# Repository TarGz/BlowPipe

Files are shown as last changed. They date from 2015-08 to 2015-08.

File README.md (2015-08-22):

=====
```
 		 ____   ____    _    ____    ____  _     ___  ______        ______ ___ ____  _____ 
 		/ ___| / ___|  / \  |  _ \  | __ )| |   / _ \|  _ \ \      / /  _ \_ _|  _ \| ____|
 		\___ \| |     / _ \ | | | | |  _ \| |  | | | | |_) \ \ /\ / /| |_) | || |_) |  _|  
 		 ___) | |___ / ___ \| |_| | | |_) | |__| |_| |  __/ \ V  V / |  __/| ||  __/| |___ 
 		|____/ \____/_/   \_\____/  |____/|_____\___/|_|     \_/\_/  |_|  |___|_|   |_____|	                                                       

```

=======

# A Parametric BlowPipe that works with Nerf Elite Dart
> Inspire by [Franck Youdine](https://twitter.com/fyoudine) Nerf darts paper blowpipe 

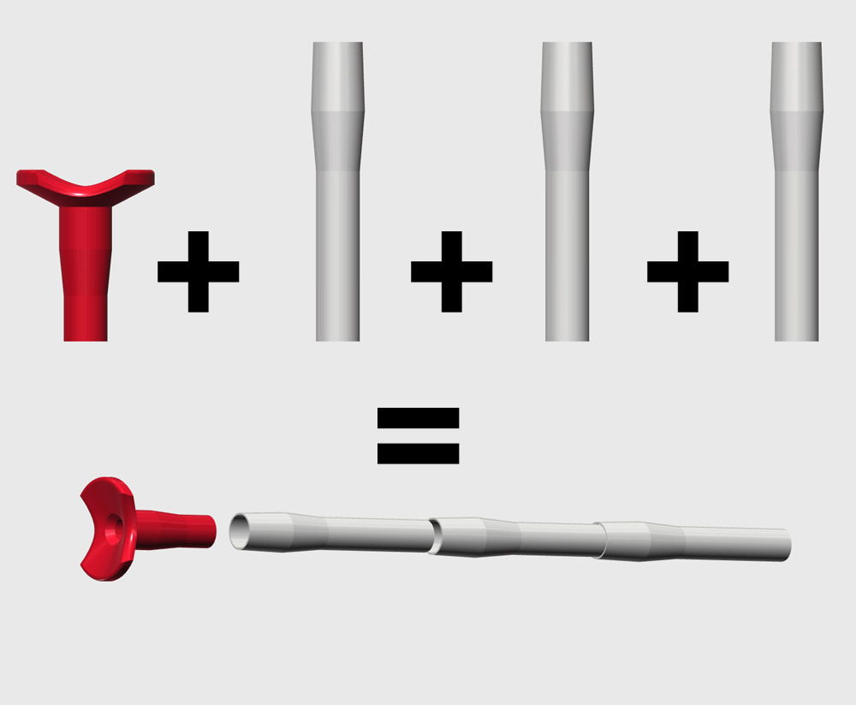
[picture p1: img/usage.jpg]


## DISCLAIMER

You are using this at your own risks, darts are relatively safe but can still hurts eyes. I can not been made responsible of any stupid things you will do with this. 

## LICENSE



Scad BlowPipe by [@targz](https://twitter.com/TarGz) is licensed under a [Creative Commons Attribution-NonCommercial 4.0 International License](http://creativecommons.org/licenses/by-nc/4.0/).

## ABOUT

This project have been tested and developed to fire Nerf Elite Dart but may be adapted to fire darts in the futur.  

Foam darts are fun, specially in office opens pace, but dart gun are not very powerful and not accurate at all.
We have used them a lot in the office and then Franck Youdine made a paper blowpipe to send darts. It was so accurate and so powerful that I decided to build one using my 3D printer.

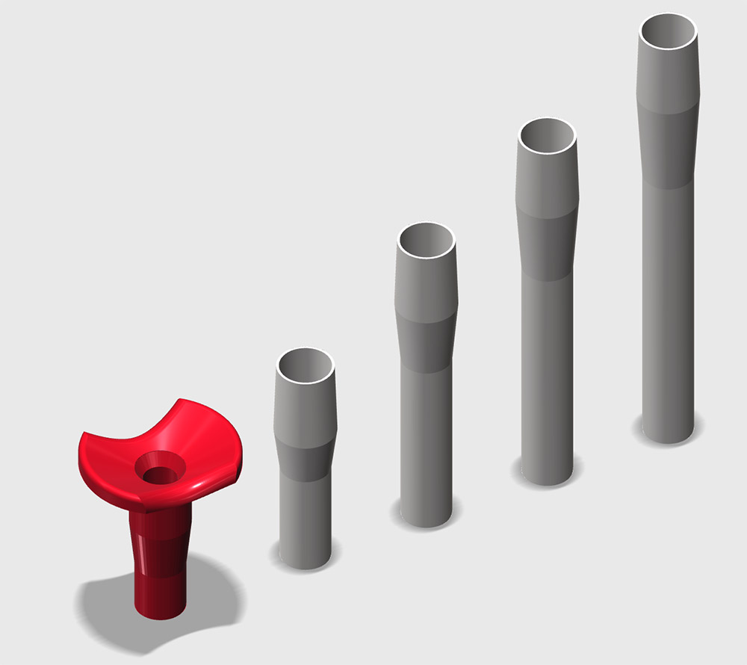
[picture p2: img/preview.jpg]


The longer the pipe the more it will be accurate, it was a bit challenging to print a long pipe has pipe need to be printed vertically. That were I came with the idea of module that could be connected and printed separately.

Depending of you printer maximum print height you can use the script to generate pipe of the perfect height. The blow module make the pipe confortable and efficient.

To stabilise the darts during the flight I get this idea of [Rifling](https://en.wikipedia.org/wiki/Rifling) so you have an option to add some groove inside the pipe. Still not sure of the efficiency, I need to get a high frame rate camera to check if the darts are rotating during the flight.

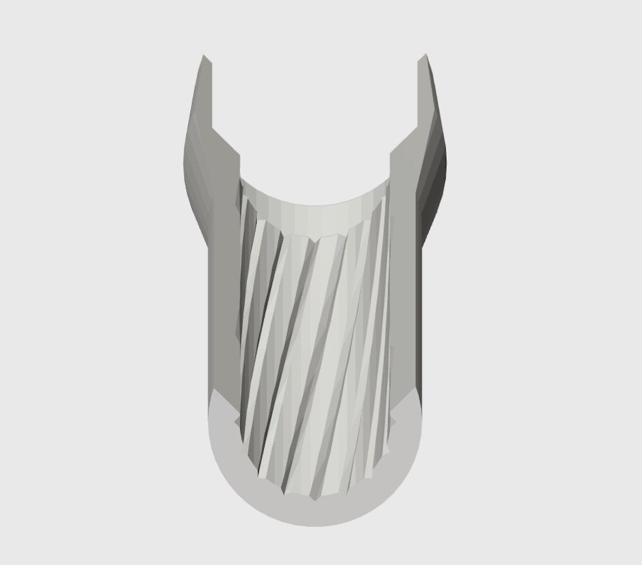
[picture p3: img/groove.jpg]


## REQUIREMENTS

You will need:

- [OpenScad](http://www.openscad.org/) free software to generate the blowpipes stl.
- A 3D printer and some PLA
- Some Nerf Elite Dart

## How to

After installing [OpenScad](http://www.openscad.org/) just use it to open the ```demo.scad``` file.
The screen should preview the pipe below. 

Then use the code below or uncomment different part of the demo file to generate your pipes.

>  First you need to include the lib

```
include <scad_blowpipe.scad>;
```

## check the demo

```
/**
 * @param {boolean} HasGroove
 */
demo(true); 
```

## generate the blow module

```
/**
 * @param {number} PipeLength
 * @param {boolean} HasGroove
 */
blow(length,groove); 
```

##  generate pipes

```
/**
 * @param {number} PipeLength
 * @param {boolean} HasGroove
 */
pipe(length,groove);
```

## ADVANCED PARAMETERS

```

/** LENGTH **/
$fn                 =   50;         // Mesh quality (number of fragments ) default:50
fix_length          =   20;         // Length of the connectors default:20
fix_ease            =   .15;        // ease between pipe to connect them default:0.15

/** PIPE **/
internal_radius     =   6.7;        // fine for standard Nerf arrow // .5 inch ? default:6.7
external_radius     =   9.5;        // radius of the pipe  default:9.5

/** ENTRANCE  **/
entrance_radius     =   6.5;        // Manage the pressure on the arrow in the entrance, more pressure = more speed = harder to blow. default:6.5
entrance_length     =   20;         // entrance length should also have an impact on speed. defaulot:20

/** GROOVE  **/
groove_twist        =   45;         // number of rotation per module default:45;
groove_size         =   1;          // Size of the groove (must not be bigger than External radius - Internal radius default:1
groove_number       =   16;         // Number of groove default:16;

```

## 3D PRINTING

Those part should be printed as they came out of the script without any support.

```
material 			: PLA
infill				: 10% 
layer heigth		: 0.3mm
Top solid layer 	: 3
Bottom solid layer 	: 3
Outline perimeter 	: 2
```

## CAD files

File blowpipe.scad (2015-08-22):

/* --------------------------------------------------------------------------------------*/
/*   ____   ____    _    ____    ____  _     ___  ______        ______ ___ ____  _____   */
/*  / ___| / ___|  / \  |  _ \  | __ )| |   / _ \|  _ \ \      / /  _ \_ _|  _ \| ____|  */
/*  \___ \| |     / _ \ | | | | |  _ \| |  | | | | |_) \ \ /\ / /| |_) | || |_) |  _|    */
/*   ___) | |___ / ___ \| |_| | | |_) | |__| |_| |  __/ \ V  V / |  __/| ||  __/| |___   */
/*  |____/ \____/_/   \_\____/  |____/|_____\___/|_|     \_/\_/  |_|  |___|_|   |_____|  */
/*                                                                                       */
/* --------------------------------------------------------------------------------------*/



/* --------------------------------------------------------------------------------------*/
/*                                                                                       */
/*           Parametric BlowPipe for Nerf darts by @targz (Julien Terraz)                */
/*           This work is licensed under the Creative Commons Attribution                */
/*           NonCommercial 4.0 International License. To view a copy of this             */
/*           license, visit http://creativecommons.org/licenses/by-nc/4.0/.              */
/*                                                                                       */
/* --------------------------------------------------------------------------------------*/



/* ------------------------------------------------------------------------------------- */
/*                                      SETTINGS                                         */
/* ------------------------------------------------------------------------------------- */

/** LENGTH **/
$fn                 =   50;         // Mesh quality (number of fragments ) default:50
fix_length          =   20;         // Length of the connectors default:20
fix_ease            =   .15;        // ease between pipe to connect them default:0.15

/** PIPE **/
internal_radius     =   6.7;        // fine for Nerf Elite Dart (.5 inch)  default radius:6.7mm
external_radius     =   9.5;        // radius of the pipe  default:9.5

/** ENTRANCE  **/
entrance_radius     =   6.5;        // Manage the pressure on the arrow in the entrance, more pressure = more speed = harder to blow. default:6.5
entrance_length     =   20;         // entrance length should also have an impact on speed. defaulot:20

/** GROOVE  **/
groove_twist        =   45;         // number of rotation per module default:45;
groove_size         =   1;          // Size of the groove (must not be bigger than External radius - Internal radius default:1
groove_number       =   16;         // Number of groove default:16;




/* ------------------------------------------------------------------------------------- */
/*                                        PUBLIC                                         */
/* ------------------------------------------------------------------------------------- */

/**  BLOW MODULE
 *
 * @param {number} PipeLength
 * @param {boolean} HasGroove
 *
 */
module blow(pl,asGroove){
    color("red") 
    rotate([180,0,0]) translate([0,0,-pl]) union(){
        blowMod(pl);
        main_pipe(pl,asGroove);
    }
}

/** BLOW PIPE   
 * 
 * @param {number} PipeLength
 * @param {boolean} HasGroove
 *
 */
module pipe(pl,asGroove){
    color("white") 
    rotate([180,0,0]) translate([0,0,-pl]) union(){
        pipeConnector(pl,asGroove);
        main_pipe(pl,asGroove);
    }
}


/** DEMO
 * 
 * @param {boolean} hasGroove
 *
 */
module demo(asGroove){
    translate([0,0,0])      blow(60,asGroove);
    translate([50,0,0])     pipe(90,asGroove);
    translate([100,0,0])    pipe(130,asGroove);
    translate([150,0,0])    pipe(160,asGroove);
    translate([200,0,0])    pipe(190,asGroove);
}

/* ------------------------------------------------------------------------------------- */
/*                        ADVANCED SETTING FROM HERE DO NOT EDIT                         */
/* ------------------------------------------------------------------------------------- */

debug                       =   false;
groove_angle                =   360 / groove_number;
fix_width                   =   2;
fix_pipe_overlap            =   1;
blow_tube_width             =   2;
blow_radius                 =   external_radius+blow_tube_width;
fix_length_blow             =   5;                      // length of the blow module connector
fix_connector_length        =   .5;         // Length ratio // deprecated
fix_connector_length_ratio  =   .2;    // Regarding the pipe length
studW                       =   3;
studH                       =   2;
studL                       =   0;
studP                       =   5;


/* ------------------------------------------------------------------------------------- */
/*                                       PRIVATE                                         */
/* ------------------------------------------------------------------------------------- */

/** STUD
    *  
    *  @param {number} width
    *  @param {number} height
    *  @param {number} heigth
    *  @param {number} depth
    *  
    */

module stud(w,l,h,d){
    echo("stud",w);
    translate([-w/2,-l/2,0]) union(){
        cube(size = [w,l,h], center = false);
        polyhedron(
          points=[  [0,-l,h],[w,-l,h],[w/2,0,h+d], 
                    [0,l,h],[w,l,h],[w/2,0,h+d] // side triangle
                    ],       
          faces=[ [2,1,0],[3,4,5],   // side triangle
                  [3,2,0],[3,5,2],[1,2,5],[4,1,5],    // roof
                  [0,1,4],[4,3,0]
                  ]  
         );
    }
}





/** GROOVES
 *
 * @param {number} PipeLength
 *
 */
module groove(pl){
    length =   pl-fix_length; 
    linear_extrude(height = length, center = false, convexity = 1, twist = groove_twist)
        translate([internal_radius+groove_size/2, 0, 0])
        rotate([0,0,-135]) polygon(points=[[0,0],[groove_size,0],[0,-groove_size]], paths=[[0,1,2]]);
}
module grooves(pl){
    color("white") union() for ( i = [0 : groove_number] ){
        rotate([0,0,groove_angle*i]) groove(pl);
    } 
}

/** MAIN PIPE
 *
 * @param {number} PipeLength
 * @param {boolean} HasGroove
 *
 */
module main_pipe(pl,asGroove){
        // MAIN PIPE
        length =   pl-fix_length; 
        translate([0, 0, fix_length]) { 
            difference(){
                color("red") difference(){
                    cylinder(length,r=external_radius);
                    translate([0, 0, -5]) cylinder(length+10,r=internal_radius);
                }
                echo("asGroove",asGroove);
                if(asGroove) grooves(pl);
            } 

        } 
        // STUD
        if(asGroove) rotate([0,0,-90-groove_twist]) translate([0, blow_radius-blow_tube_width+studH/2, length-fix_ease]) stud(studW,studH,studL,studP); 

}

/** PIPES CONNECTOR
 *
 * @param {number} PipeLength
 *
 */
module pipeConnector(pl,asGroove){
     difference(){
         // CONNECTOR
         translate([0, 0, fix_length]) {
            radius1 = external_radius+fix_width+fix_ease;
            // FIX PIPE
            color("grey")  translate([0, 0, -fix_length]) difference(){
                cylinder(fix_length,r1=external_radius+fix_width+fix_ease-1,r2=radius1);
                translate([0, 0, -5]) cylinder((fix_length)+10,r=external_radius+fix_ease);
             }
            // FIX CONNECTOR
            color("orange")  translate([0, 0, 0]) difference(){
                cylinder(pl*fix_connector_length_ratio,r1=radius1,r2=external_radius);
                translate([0, 0, -5]) cylinder((pl*fix_connector_length_ratio+10),r=external_radius);
             }   

            
         }
         // STUD
         if(asGroove) rotate([0,0,-90]) translate([0, blow_radius-blow_tube_width+studH/2, -studL]) stud(studW,studH,studL,studP);  
    }
}
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

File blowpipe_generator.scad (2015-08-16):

// ----------------------------------------------------------------------------
// Parametric BlowPipe for Nerf dart by @targz Julien Terraz
// It is licensed under the Creative Commons 1.0 Universal
// ----------------------------------------------------------------------------


// LENGTH
number_of_pipe=4;
printer_max_height = 150;
fix_length=30;
fix_connector_length=printer_max_height/2;


// PIPE
internal_radius     = 7; // do not change fine for standart Nerf arrow // .5 inch ?
entrance_radius     = 6; // manage the pressure on the arrow in the entrance
entrance_length     = 4;
external_radius     = 9.5; 



// GROOVE
groove_twist = 180; // number of rotation per module default:90;
groove_size = 2;  // Size of the groove (must not be bigger than External radius - Internal radius default:2
groove_number = 5; // Number of groove default:4;


// PRIVATE DO NOT EDIT FROM HHERE
groove_angle = 360/groove_number;
fix_ease=.5; //
fix_width = external_radius-internal_radius;

fix_pipe_overlap=1;

length = printer_max_height-fix_length; // total length of the BlowPipe
blow_radius = external_radius+2;

// GROOVE
module groove(){
    linear_extrude(height = length, center = false, convexity = 1, twist = groove_twist)
        translate([internal_radius+groove_size/2, 0, 0])
        rotate([0,0,-135]) polygon(points=[[0,0],[groove_size,0],[0,-groove_size]], paths=[[0,1,2]]);
}


module grooves(){
    union() for ( i = [0 : groove_number] ){
        rotate([0,0,groove_angle*i]) groove();
    } 
}

module main_pipe(){
            // MAIN PIPE
        translate([0, 0, fix_length])  
            difference(){
                difference(){
                    cylinder(length,r=external_radius);
                    translate([0, 0, -5]) cylinder(length+10,r=internal_radius);
                }
                grooves();
            }  
}




module pipeConnector(){
    
     translate([0, 0, fix_length]) {
        // FIX PIPE
        translate([0, 0, -fix_length]) difference(){
            cylinder(fix_length,r1=external_radius+fix_width+fix_ease-1,r2=external_radius+fix_width+fix_ease);
            translate([0, 0, -5]) cylinder((fix_length)+10,r=external_radius+fix_ease);
         }
         // FIX CONNECTOR
         translate([0, 0, 0]) difference(){
            cylinder(fix_connector_length,r1=external_radius+fix_width+fix_ease,r2=external_radius);
            translate([0, 0, -5]) cylinder((fix_connector_length)+10,r=external_radius);
         }     
     }
}

module blow(){
    difference(){

         translate([0, 0, fix_length]) {
            union(){
                // LIPS COONTACT PIPE
                translate([0, 0, -fix_length]) difference(){
                    cylinder(fix_length,r=blow_radius);
                    translate([0, 0, -5]) cylinder((fix_length)+10,r=external_radius+fix_ease);
                 }
                 // PRESURE MANAGER
                 union(){
                     // cone down
                     color("grey") translate([0, 0, 0]) difference(){
                        cylinder(entrance_length,r1=blow_radius,r2=external_radius);
                        translate([0, 0, -.1]) cylinder(entrance_length+.2,r1=entrance_radius,r2=external_radius);
                     }         
                     // ring
                     color("purple") translate([0, 0, -entrance_length]) difference(){
                        cylinder(entrance_length,r=blow_radius);
                        translate([0, 0, -1]) cylinder(entrance_length+2,r=entrance_radius);
                     }   
                     // cone up
                     color("white") translate([0, 0, -fix_length]) difference(){
                        cylinder(fix_length-entrance_length,r1=blow_radius,r2=blow_radius);
                        translate([0, 0, -.1]) cylinder(fix_length-entrance_length+.2,r1=external_radius,r2=entrance_radius);
                     }   
                }
                 
                 
                 // CONE
                 color("green")  translate([0, 0, 0]) difference(){
                    cylinder(fix_connector_length,r1=blow_radius,r2=external_radius);
                    translate([0, 0, -5]) cylinder((fix_connector_length)+10,r=external_radius);
                 }     
            }  
        }
         // LIPS CURVE   
         union(){
            //cylinder(10,r1=external_radius+10,r2=1);  
            scale([2.25,1,1])rotate([90,90,0])  translate([8,0,-50]) cylinder(100,r=external_radius); 
         }
    }  
}

module blowPipe(){
    blow();
    main_pipe();
}

module pipe(){
     union(){
        pipeConnector();
        main_pipe();
    }
}

module pipes(){
    
    for ( i = [0 : number_of_pipe-1] ){
        if(i==0){
            blowPipe();
        }else{
            translate([(i*external_radius)*5,0,0]) pipe();
        }
    }
}

// MAIN
rotate([180,0,0]) translate([0,0,-printer_max_height]) pipes();

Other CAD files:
scad_blowpipe.scad
demo.scad

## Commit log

2015-08-07 4 150mm pipes
    [blowpipe_150x4.stl]
2015-08-16 Update blow pipe
    [blowpipe_150x4.stl, blowpipe_generator.scad]
2015-08-16 code clean + refactor API
    [blowpipe.scad, blowpipe_70xr7.stl, demo.scad]
2015-08-16 refactor API update doc
    [blowpipe.scad, demo.scad]
2015-08-16 adding examples fliles
    [blow_module_70.stl, blowpipe_100.stl, blowpipe_150.stl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]
2015-08-16 Fix bug + update doc with preview images
    [blowpipe.scad, blowpipe_100.stl, blowpipe_150.stl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]
2015-08-17 doc update
    [demo.scad]
2015-08-18 Remove STL
2015-08-18 removing stl
    Compile them using OpenScad
    [blow_module_70.stl, blowpipe_100.stl, blowpipe_150.stl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]
2015-08-18 Demo update
    [blowpipe.scad, demo.scad]
2015-08-18 quality tweaks
    [blowpipe.scad, demo.scad]
2015-08-18 Optional Groove & tweak internal radius
    [blowpipe.scad, demo.scad]
2015-08-19 The new Lips connector
    [blowpipe.scad, demo.scad]
2015-08-19 Code cleanup
    [blowpipe.scad, demo.scad]
2015-08-21 Tweaking groove
    [blowpipe.scad]
2015-08-21 adding a Stud to align groove
    [blowpipe.scad, demo.scad]
2015-08-21 Update DOC
    [blowpipe.scad, demo.scad]
2015-08-22 License update
    Moving to creativecommons non commercial use
    [blowpipe.scad, demo.scad]
2015-08-22 Stud only when pipe has groove
    [blowpipe.scad, demo.scad]
2016-03-27 FIX Connector width
    [scad_blowpipe.scad]
